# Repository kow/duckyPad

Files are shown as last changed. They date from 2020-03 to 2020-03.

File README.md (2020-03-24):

# duckypad: Scriptable Mechanical Keypad with RGB Backlight



duckypad is a mechanical keypad with RGB backlight, OLED screen, and 15 keys. Each key can execute a script when pressed.

The scripts can be as simple as shortcuts like `ctrl+c`, or as complex as [creating root backdoors](https://github.com/hak5darren/USB-Rubber-Ducky/wiki/Payload---OSX-Root-Backdoor) or [grabbing passwords](https://github.com/hak5darren/USB-Rubber-Ducky/wiki/Payload---download-mimikatz%2C-grab-passwords-and-email-them-via-gmail). It's all customizable by you.

Multiple profiles are supported, for different programs/environments.

## Features

* 15 mechanical switches
* Individually addressable RGB backlights with animations
* OLED screen displaying current profile and key functions
* SD card script storage
* Standard duckyscript parsed onboard
* Multiple profiles
* USB-C connector

## Video

Here's a silly video showing duckypad in action, as well as the timelapse of me building it.

https://www.youtube.com/watch?v=EGLLCtRuEuM

## Getting started

Please see [this guide](./getting_started.md) on how to use your duckypad.

## Making one yourself

Please see [this guide](./build_it_yourself.md).

## Questions?

Feel free to ask in the issue section, or email me at `dekunukem__gmail__com`.

## kowmod1 ##

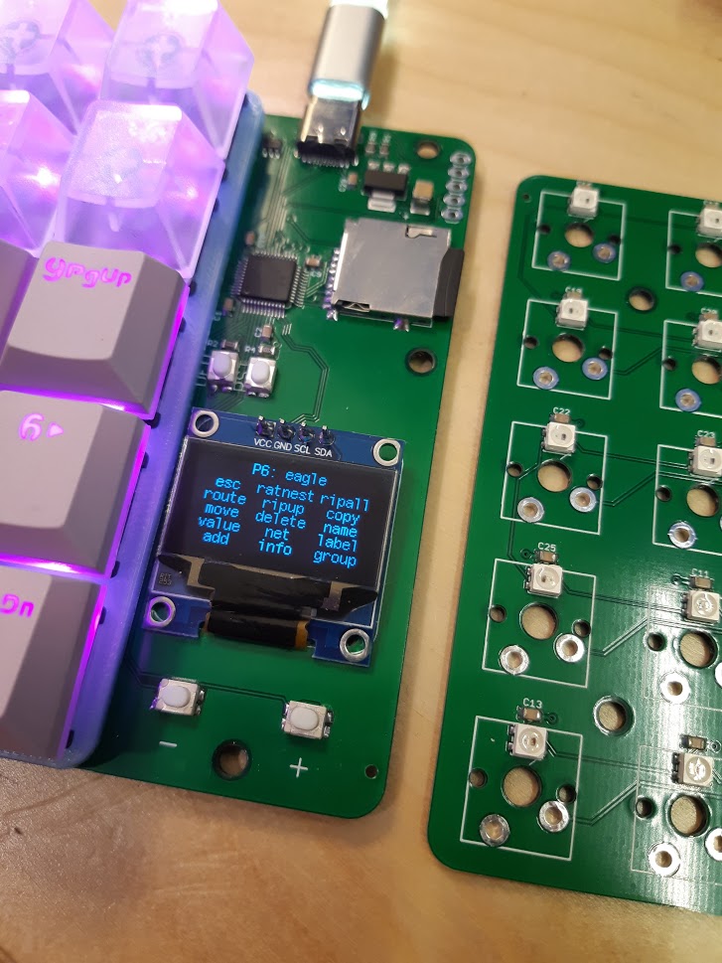
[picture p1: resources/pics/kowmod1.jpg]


replaced LCD with cheaper 4 pin version, uses any ~$3 128x64 oled LCD with VCC,GND,SCL,SDA pinout order (https://www.ebay.ca/itm/0-96-I2C-IIC-SPI-Serial-128X64-White-OLED-LCD-LED-Display-Module-for-Arduino-LR/392728983410)
replaced sk6812 mini with ws2812b mini, added gerber, bom, and cpl for jlcpcb assembly

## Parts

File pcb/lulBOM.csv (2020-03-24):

Comment | Designator | Footprint | LCSC Part #(optional)
100nF | C1,C2,C9,C10,C11,C12,C13,C14,C15,C16,C17,C18,C19,C20,C21,C22,C23,C24,C25,C29 | 0805@1 | C49678
47uF | C27 | C1210 | C77101
STM32F072C8T6 | IC1 | TQFP48 | C80488
REG1117 | IC2 | SOT223 | C6186
74AHCT1G08DBV | IC3 | SOT23-5 | C113521
WS2812B-MINI | LED1,LED2,LED3,LED4,LED5,LED6,LED7,LED8,LED9,LED10,LED11,LED12,LED13,LED14,LED15 | WS2812B-MINI | C114583
5.1K | R1,R9 | 0805 | C27834
10K | R2,R4,R5 | 0805 | C17414
TF-HOLDER | SD1 | TF-PULL | C111196
324_SW324_SWITCH_FOOT_HOLE | SW1,SW2,SW3,SW4 | 342_SWICH_FOOT_HOLE | C115360
USBC_16P | U2 | USBC_16P_FOOT | C393939

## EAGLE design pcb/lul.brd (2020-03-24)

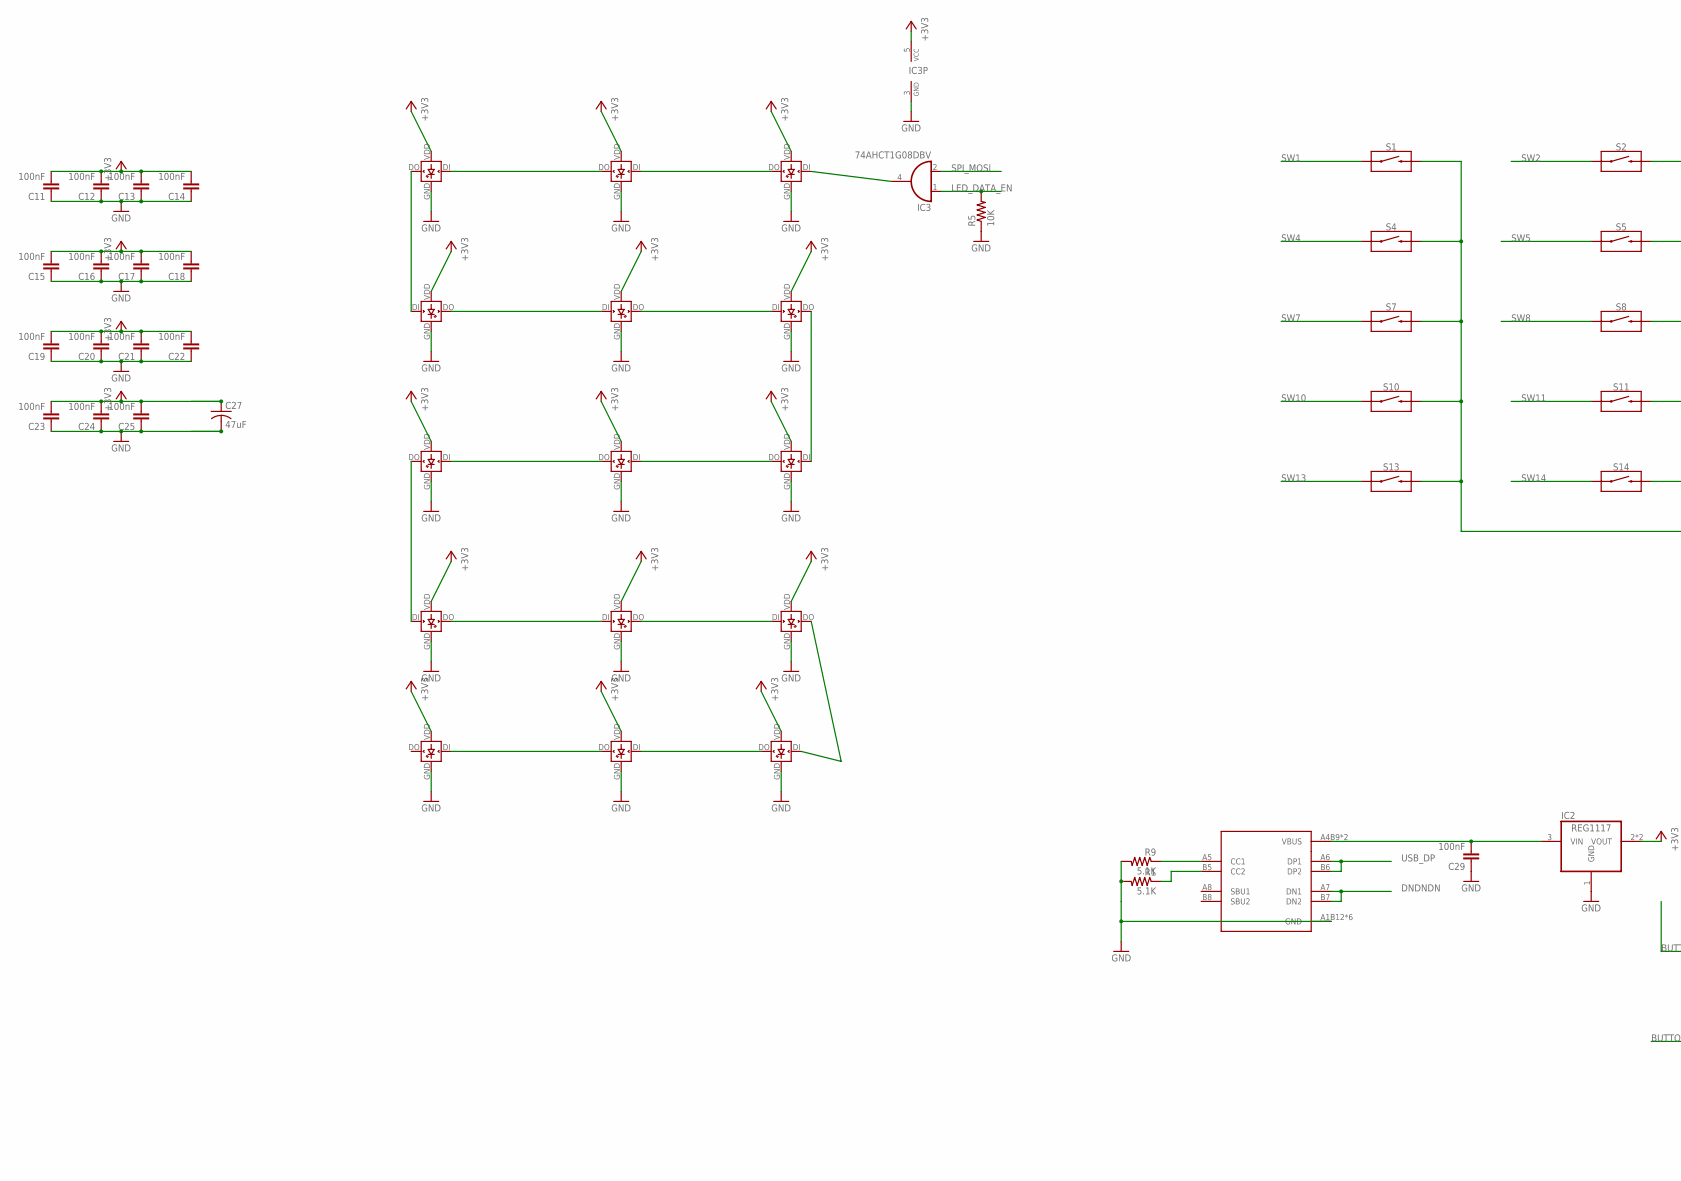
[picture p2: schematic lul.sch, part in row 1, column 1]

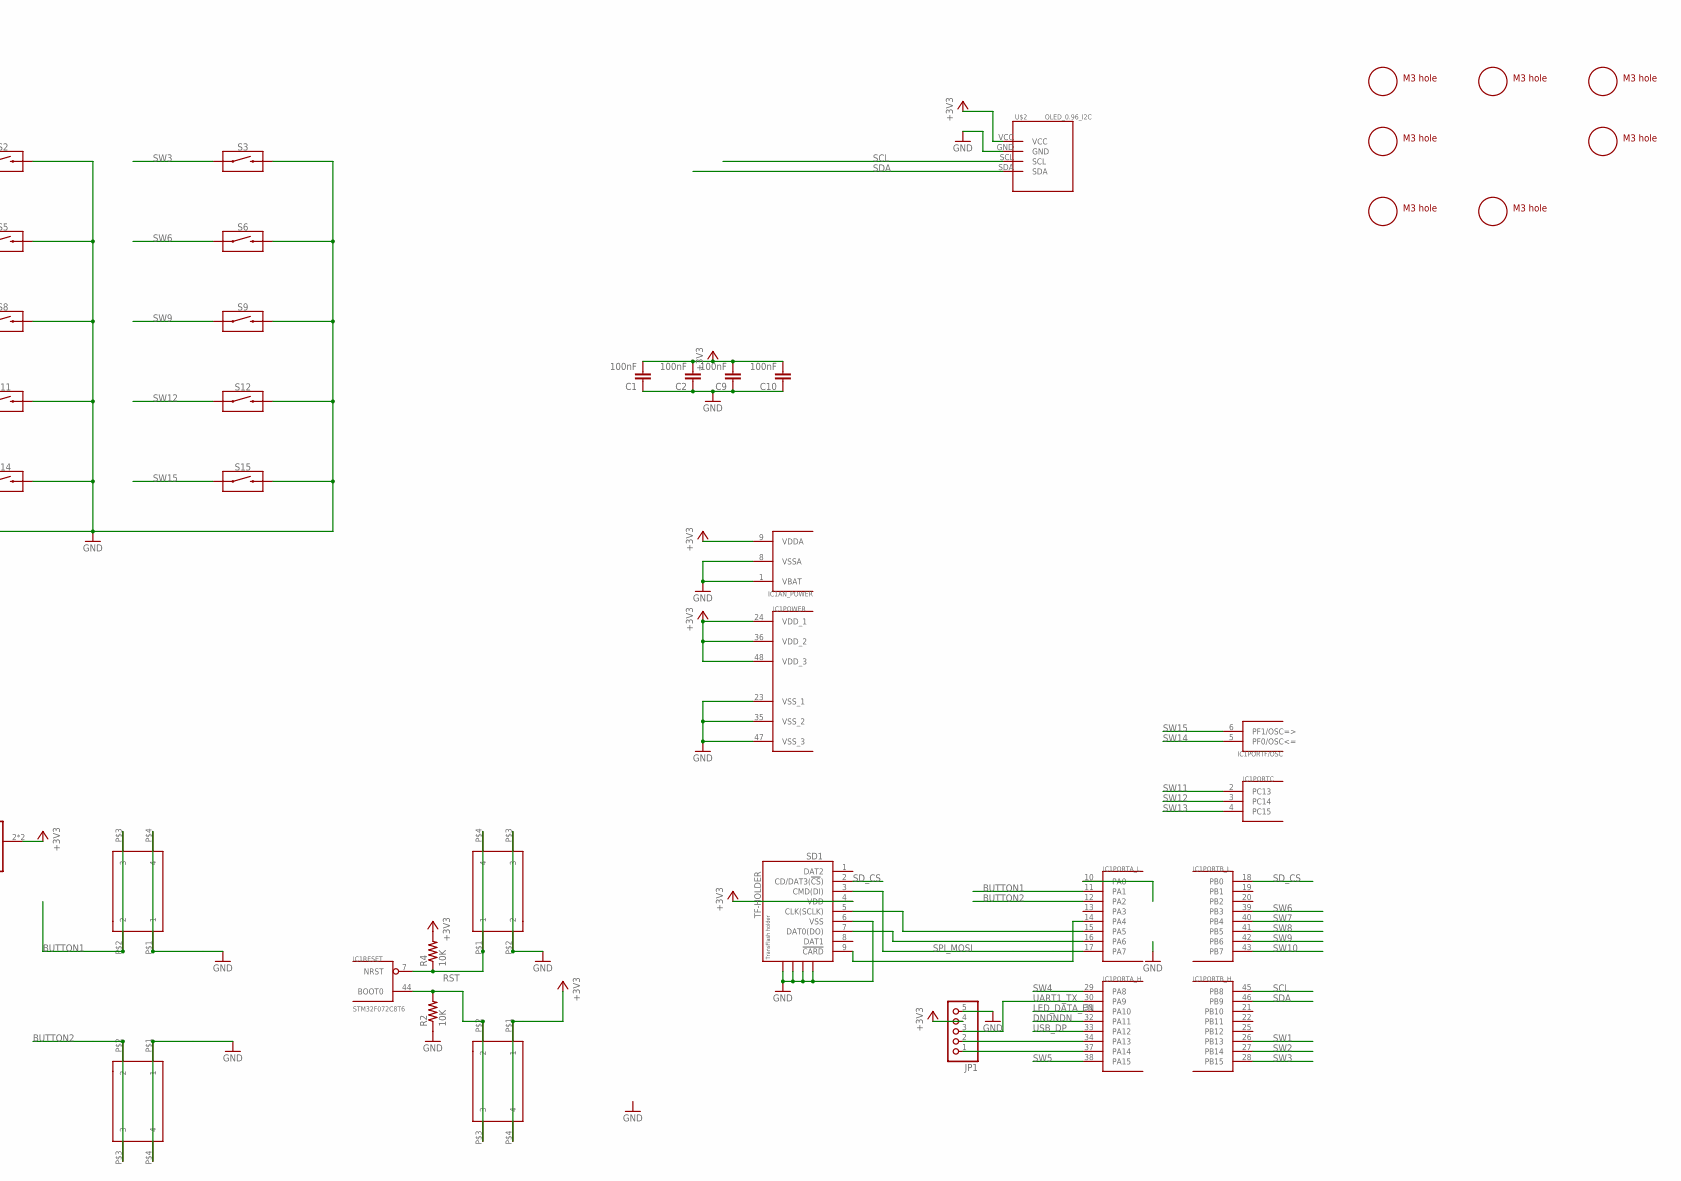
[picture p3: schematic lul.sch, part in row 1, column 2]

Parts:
C1, C2, C9, C10, C11, C12, C13, C14, C15, C16, C17, C18, C19, C20, C21, C22, C23, C24, C25, C29: 100nF; 0805@1
C27: 47uF; C1210
IC1: STM32F072C8T6; TQFP48
IC2: REG1117; SOT223
IC3: 74AHCT1G08DBV; SOT23-5
JP1: PINHD-1X5; 1X05
LED1, LED2, LED3, LED4, LED5, LED6, LED7, LED8, LED9, LED10, LED11, LED12, LED13, LED14, LED15: WS2812B-MINI
R1, R9: 5.1K; 0805
R2, R4, R5: 10K; 0805
S1, S2, S3, S4, S5, S6, S7, S8, S9, S10, S11, S12, S13, S14, S15: CHERRY-MX-LED
SD1: TF-HOLDER; TF-PULL
SW1, SW2, SW3, SW4: 324_SW324_SWITCH_FOOT_HOLE; 342_SWICH_FOOT_HOLE
U2: USBC_16P; USBC_16P_FOOT
U$2: OLED_0.96_I2C
U$7, U$9, U$10, U$11, U$14, U$15, U$16: M3_MOUNTING_HOLE; M3_MOUNTING_HOLE_PACK

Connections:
+3V3: C1.2, C2.2, C9.2, C10.2, C11.2, C12.2, C13.2, C14.2, C15.2, C16.2, C17.2, C18.2, C19.2, C20.2, C21.2, C22.2, C23.2, C24.2, C25.2, C27.1, IC1.9 (VDDA), IC1.24 (VDD_1), IC1.36 (VDD_2), IC1.48 (VDD_3), IC2.2 (VOUT), IC2.4 (VOUT), IC3.5 (VCC), JP1.4, LED1.VDD, LED2.VDD, LED3.VDD, LED4.VDD, LED5.VDD, LED6.VDD, LED7.VDD, LED8.VDD, LED9.VDD, LED10.VDD, LED11.VDD, LED12.VDD, LED13.VDD, LED14.VDD, LED15.VDD, R4.2, SD1.4 (VDD), SW1.P$1 (1), SW1.P$4 (4), U$2.VCC
BUTTON1: IC1.11 (PA1), SW3.P$2 (2), SW3.P$3 (3)
BUTTON2: IC1.12 (PA2), SW4.P$2 (2), SW4.P$3 (3)
DNDNDN: IC1.32 (PA11), U2.A7 (DN1), U2.B7 (DN2)
GND: C1.1, C2.1, C9.1, C10.1, C11.1, C12.1, C13.1, C14.1, C15.1, C16.1, C17.1, C18.1, C19.1, C20.1, C21.1, C22.1, C23.1, C24.1, C25.1, C27.2, C29.1, IC1.1 (VBAT), IC1.8 (VSSA), IC1.23 (VSS_1), IC1.35 (VSS_2), IC1.47 (VSS_3), IC2.1 (GND), IC3.3 (GND), JP1.5, LED1.GND, LED2.GND, LED3.GND, LED4.GND, LED5.GND, LED6.GND, LED7.GND, LED8.GND, LED9.GND, LED10.GND, LED11.GND, LED12.GND, LED13.GND, LED14.GND, LED15.GND, R1.2, R2.1, R5.1, R9.2, S1.S2, S2.S2, S3.S2, S4.S2, S5.S2, S6.S2, S7.S2, S8.S2, S9.S2, S10.S2, S11.S2, S12.S2, S13.S2, S14.S2, S15.S2, SD1.6 (VSS), SD1.S1, SD1.S2, SD1.S3, SD1.S4, SW2.P$2 (2), SW2.P$3 (3), SW3.P$1 (1), SW3.P$4 (4), SW4.P$1 (1), SW4.P$4 (4), U2.A1B12 (GND), U2.B11A12 (GND), U2.P$13 (GND), U2.P$14 (GND), U2.P$15 (GND), U2.P$16 (GND), U$2.GND
LED_DATA_EN: IC1.31 (PA10), IC3.1 (I0), R5.2
unnamed: C29.2, IC2.3 (VIN), U2.A4B9 (VBUS), U2.B4A9 (VBUS)
unnamed: IC1.44 (BOOT0), R2.2, SW1.P$2 (2), SW1.P$3 (3)
unnamed: IC1.15 (PA5), SD1.5 (CLK(SCLK))
unnamed: LED2.DI (DIN), LED3.DO (DOUT)
unnamed: IC1.16 (PA6), SD1.7 (DAT0(DO))
unnamed: IC1.14 (PA4), SD1.9 (!CARD)
unnamed: LED1.DI (DIN), LED2.DO (DOUT)
unnamed: LED1.DO (DOUT), LED4.DI (DIN)
unnamed: LED4.DO (DOUT), LED5.DI (DIN)
unnamed: LED5.DO (DOUT), LED6.DI (DIN)
unnamed: LED6.DO (DOUT), LED9.DI (DIN)
unnamed: LED8.DI (DIN), LED9.DO (DOUT)
unnamed: LED7.DI (DIN), LED8.DO (DOUT)
unnamed: LED7.DO (DOUT), LED10.DI (DIN)
unnamed: LED10.DO (DOUT), LED11.DI (DIN)
unnamed: LED11.DO (DOUT), LED12.DI (DIN)
unnamed: LED12.DO (DOUT), LED15.DI (DIN)
unnamed: LED14.DI (DIN), LED15.DO (DOUT)
unnamed: LED13.DI (DIN), LED14.DO (DOUT)
unnamed: IC3.4 (O), LED3.DI (DIN)
unnamed: R1.1, U2.B5 (CC2)
unnamed: IC1.37 (PA14), JP1.1
unnamed: R9.1, U2.A5 (CC1)
unnamed: IC1.34 (PA13), JP1.2
OLED_RESET: IC1.10 (PA0)
RST: IC1.7 (NRST), R4.1, SW2.P$1 (1), SW2.P$4 (4)
SCL: IC1.45 (PB8), U$2.SCL
SDA: IC1.46 (PB9), U$2.SDA
SD_CS: IC1.18 (PB0), SD1.2 (CD/DAT3(!CS!))
SPI_MOSI: IC1.17 (PA7), IC3.2 (I1), SD1.3 (CMD(DI))
SW1: IC1.26 (PB13), S1.S1
SW2: IC1.27 (PB14), S2.S1
SW3: IC1.28 (PB15), S3.S1
SW4: IC1.29 (PA8), S4.S1
SW5: IC1.38 (PA15), S5.S1
SW6: IC1.39 (PB3), S6.S1
SW7: IC1.40 (PB4), S7.S1
SW8: IC1.41 (PB5), S8.S1
SW9: IC1.42 (PB6), S9.S1
SW10: IC1.43 (PB7), S10.S1
SW11: IC1.2 (PC13), S11.S1
SW12: IC1.3 (PC14), S12.S1
SW13: IC1.4 (PC15), S13.S1
SW14: IC1.5 (PF0/OSC<=), S14.S1
SW15: IC1.6 (PF1/OSC=>), S15.S1
UART1_TX: IC1.30 (PA9), JP1.3
USB_DP: IC1.33 (PA12), U2.A6 (DP1), U2.B6 (DP2)

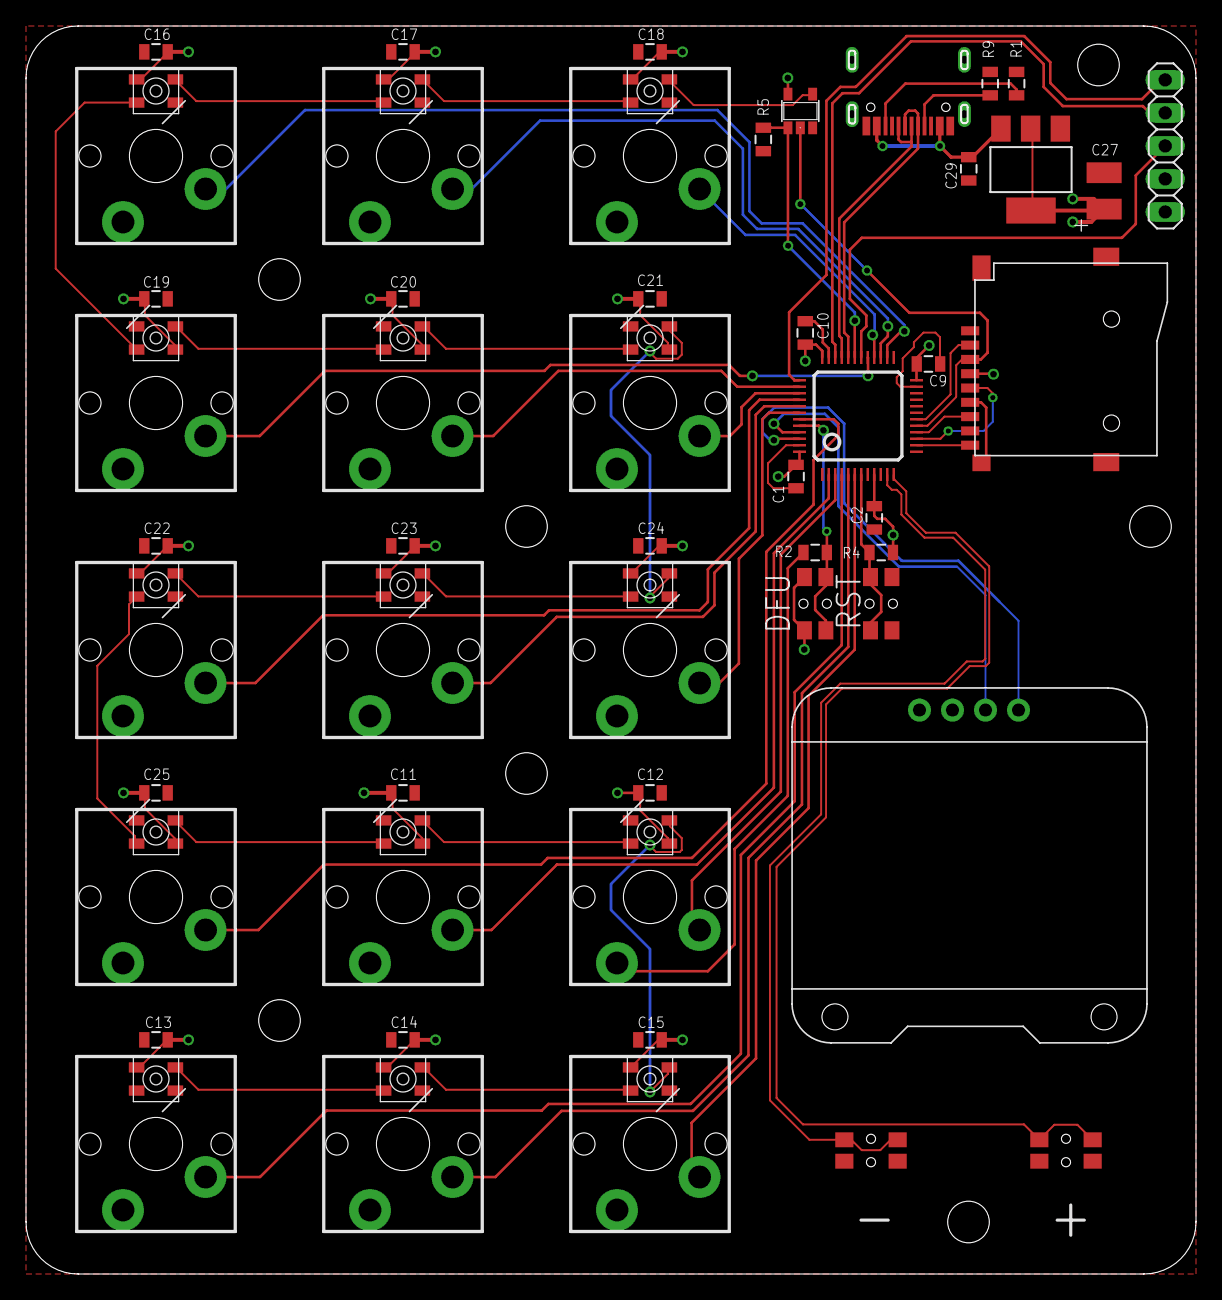
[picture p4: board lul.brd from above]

Board: 2 copper layers, 90.0 x 96.0 mm, 74 parts (0 on the bottom side), 52 nets.
